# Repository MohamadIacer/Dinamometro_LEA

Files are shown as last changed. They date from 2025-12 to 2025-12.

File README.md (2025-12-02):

# Dinamometro_LEA
Repositório de desenvolvimento do sistema de dinamometria para turbinas em escala, utilizado pelo Laboratório de Energia e Ambiente da Universidade de Brasília.

Link com arquivos SolidWorks da montagem mecânica e peças individuais: https://1drv.ms/u/c/2880bb215aad6797/IQDlmrM-lfSOQbhDQPYtA1VkAWzMAm86arUpSsEFtpBo3BE?e=ooj1fM

Link com PDF do relatório da última iteração de desenvolvimento: https://1drv.ms/b/c/2880bb215aad6797/IQATOKx8Zu7TSKCGMIeG2nDvAc81WT-9CV8OO6a27Ivx5ow?e=Kimnmw

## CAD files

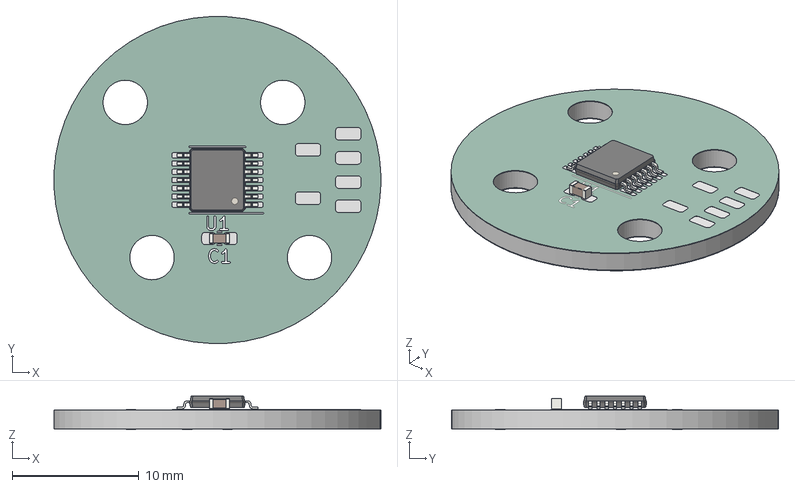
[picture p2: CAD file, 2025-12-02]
hardware/posicao/encoder_magnetico/encoder_magnetico.step
25.8 x 25.8 x 2.67 mm
TSSOP-14_4.4x5mm_P0.65mm
C_0603_1608Metric
encoder_magnetico_copper
encoder_magnetico_pad
encoder_magnetico_via
encoder_magnetico_silkscreen
encoder_magnetico_soldermask
encoder_magnetico_PCB

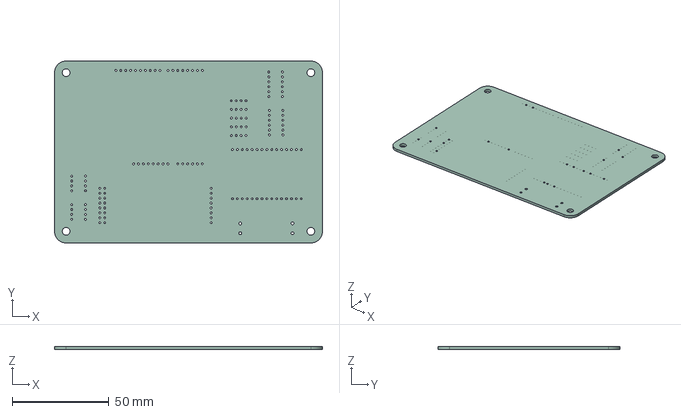
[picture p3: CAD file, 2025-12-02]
hardware/mb_geral/mb/mb1.step
138.5 x 94.0 x 1.51 mm

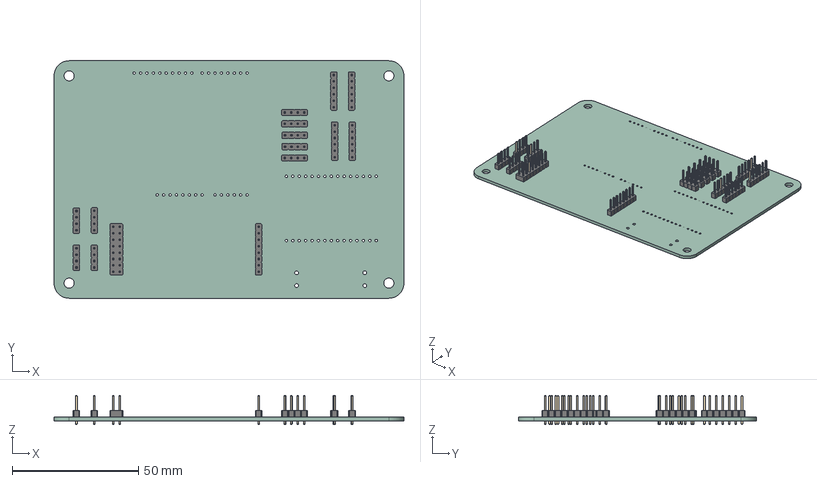
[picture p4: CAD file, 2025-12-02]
hardware/mb_geral/mb/mb.step
138.5 x 94.0 x 11.5 mm
PinHeader_1x04_P2.54mm_Vertical x 9
PinHeader_1x08_P2.54mm_Vertical
PinHeader_1x06_P2.54mm_Vertical x 4
PinHeader_2x08_P2.54mm_Vertical
mb_PCB

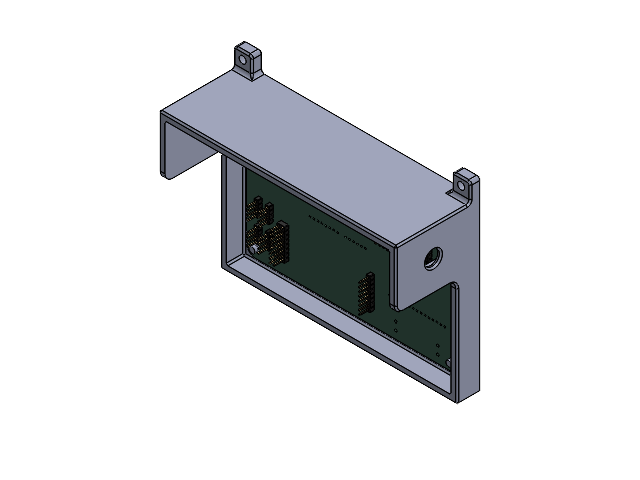
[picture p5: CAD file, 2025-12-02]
hardware/mb_geral/mb/Mont4.SLDASM
PinHeader_1x04_P2.54mm_Vertical.step x 9
PinHeader_1x08_P2.54mm_Vertical.step
PinHeader_1x06_P2.54mm_Vertical.step x 4
PinHeader_2x08_P2.54mm_Vertical.step
mb_PCB.step
case

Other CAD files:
hardware/mb_geral/mb/case.SLDPRT
hardware/mb_geral/mb/case.STL
hardware/mb_geral/mb/mb.SLDASM

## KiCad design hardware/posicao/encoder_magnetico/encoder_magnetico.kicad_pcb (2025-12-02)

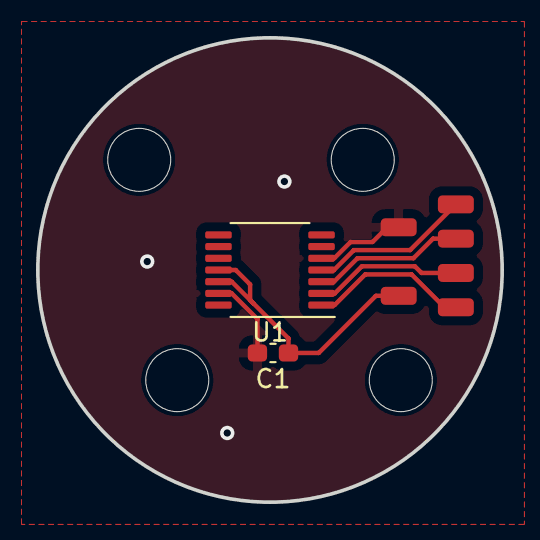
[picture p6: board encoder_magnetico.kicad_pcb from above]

Board: 2 copper layers, 25.8 x 25.8 mm, 12 parts (0 on the bottom side), 6 nets.

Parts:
3V3: Conn_01x01; SolderWirePad_1x01_SMD_1x2mm
C1: 100nF; C_0603_1608Metric_Pad1.08x0.95mm_HandSolder
CK: Conn_01x01; SolderWirePad_1x01_SMD_1x2mm
CS: Conn_01x01; SolderWirePad_1x01_SMD_1x2mm
GND: Conn_01x01; SolderWirePad_1x01_SMD_1x2mm
H1, H2, H3, H4: MountingHole; MountingHole_3.5mm
MI: Conn_01x01; SolderWirePad_1x01_SMD_1x2mm
MO: Conn_01x01; SolderWirePad_1x01_SMD_1x2mm
U1: AS5047D; TSSOP-14_4.4x5mm_P0.65mm

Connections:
3v3: 3V3.1, C1.1, U1.11 (VDD), U1.12 (VDD3V3)
CLK: CK.1, U1.2 (CLK)
CS: CS.1, U1.1 (~CS)
GND: C1.2, GND.1, U1.5 (TST), U1.13 (GND)
MISO: MI.1, U1.3 (MISO)
MOSI: MO.1, U1.4 (MOSI)

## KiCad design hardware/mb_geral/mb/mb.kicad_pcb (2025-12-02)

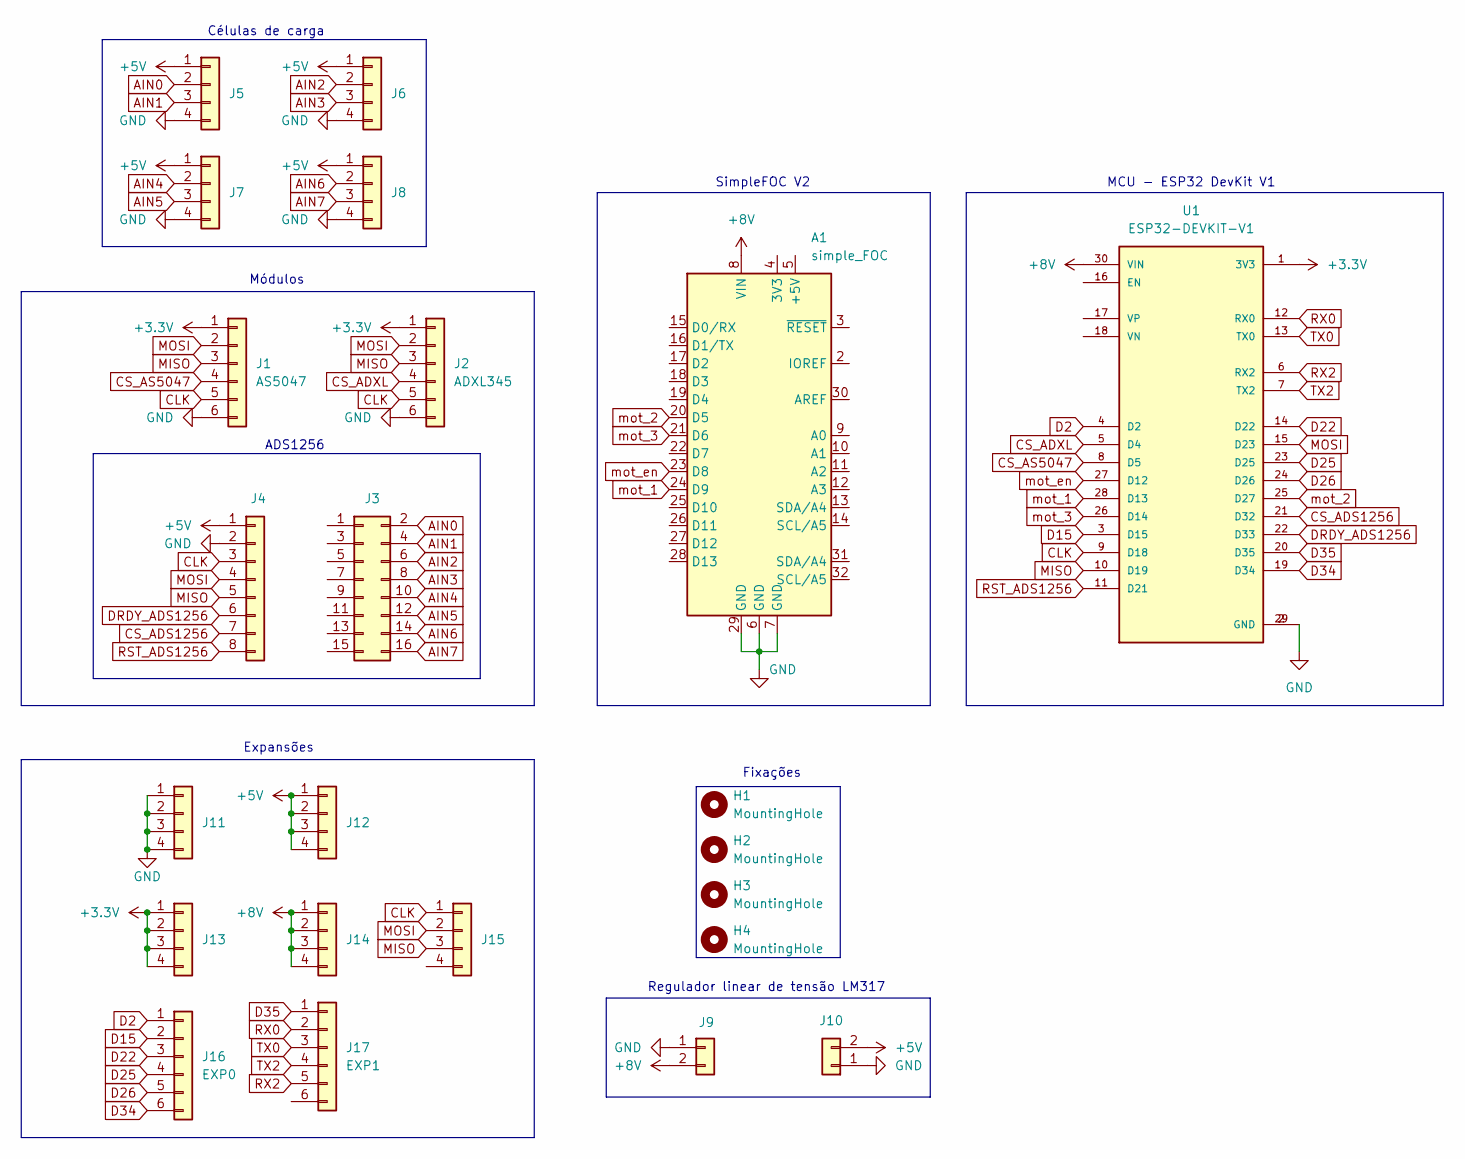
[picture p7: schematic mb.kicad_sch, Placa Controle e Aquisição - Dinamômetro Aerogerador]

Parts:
A1: simple_FOC; Arduino_UNO_R3
H1, H2, H3, H4: MountingHole; MountingHole_4mm
J1: AS5047; PinHeader_1x06_P2.54mm_Vertical
J2: ADXL345; PinHeader_1x06_P2.54mm_Vertical
J3: Conn_02x08_Top_Bottom; PinHeader_2x08_P2.54mm_Vertical
J4: Conn_01x08; PinHeader_1x08_P2.54mm_Vertical
J5, J6, J7, J8, J11, J12, J13, J14, J15: Conn_01x04; PinHeader_1x04_P2.54mm_Vertical
J9, J10: Conn_01x02; TerminalBlock_bornier-2_P5.08mm
J16: EXP0; PinHeader_1x06_P2.54mm_Vertical
J17: EXP1; PinHeader_1x06_P2.54mm_Vertical
U1: ESP32-DEVKIT-V1; MODULE_ESP32_DEVKIT_V1; PARTREV N/A

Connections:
+3.3V: J1.1, J2.1, J13.1, J13.2, J13.3, J13.4, U1.1 (3V3)
+5V: J4.1, J5.1, J6.1, J7.1, J8.1, J10.2, J12.1, J12.2, J12.3, J12.4
+8V: A1.8 (VIN), J9.2, J14.1, J14.2, J14.3, J14.4, U1.30 (VIN)
AIN0: J3.2, J5.2
AIN1: J3.4, J5.3
AIN2: J3.6, J6.2
AIN3: J3.8, J6.3
AIN4: J3.10, J7.2
AIN5: J3.12, J7.3
AIN6: J3.14, J8.2
AIN7: J3.16, J8.3
CLK: J1.5, J2.5, J4.3, J15.1, U1.9 (D18)
CS_ADS1256: J4.7, U1.21 (D32)
CS_ADXL: J2.4, U1.5 (D4)
CS_AS5047: J1.4, U1.8 (D5)
D2: J16.1, U1.4 (D2)
D15: J16.2, U1.3 (D15)
D22: J16.3, U1.14 (D22)
D25: J16.4, U1.23 (D25)
D26: J16.5, U1.24 (D26)
D34: J16.6, U1.19 (D34)
D35: J17.1, U1.20 (D35)
DRDY_ADS1256: J4.6, U1.22 (D33)
GND: A1.6 (GND), A1.7 (GND), A1.29 (GND), J1.6, J2.6, J4.2, J5.4, J6.4, J7.4, J8.4, J9.1, J10.1, J11.1, J11.2, J11.3, J11.4, U1.2 (GND), U1.29 (GND)
MISO: J1.3, J2.3, J4.5, J15.3, U1.10 (D19)
MOSI: J1.2, J2.2, J4.4, J15.2, U1.15 (D23)
RST_ADS1256: J4.8, U1.11 (D21)
RX0: J17.2, U1.12 (RX0)
RX2: J17.5, U1.6 (RX2)
TX0: J17.3, U1.13 (TX0)
TX2: J17.4, U1.7 (TX2)
mot_1: A1.24 (D9), U1.28 (D13)
mot_2: A1.20 (D5), U1.25 (D27)
mot_3: A1.21 (D6), U1.26 (D14)
mot_en: A1.23 (D8), U1.27 (D12)

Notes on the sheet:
Células de carga
Expansões
SimpleFOC V2
Módulos
ADS1256
Fixações
MCU - ESP32 DevKit V1
Regulador linear de tensão LM317

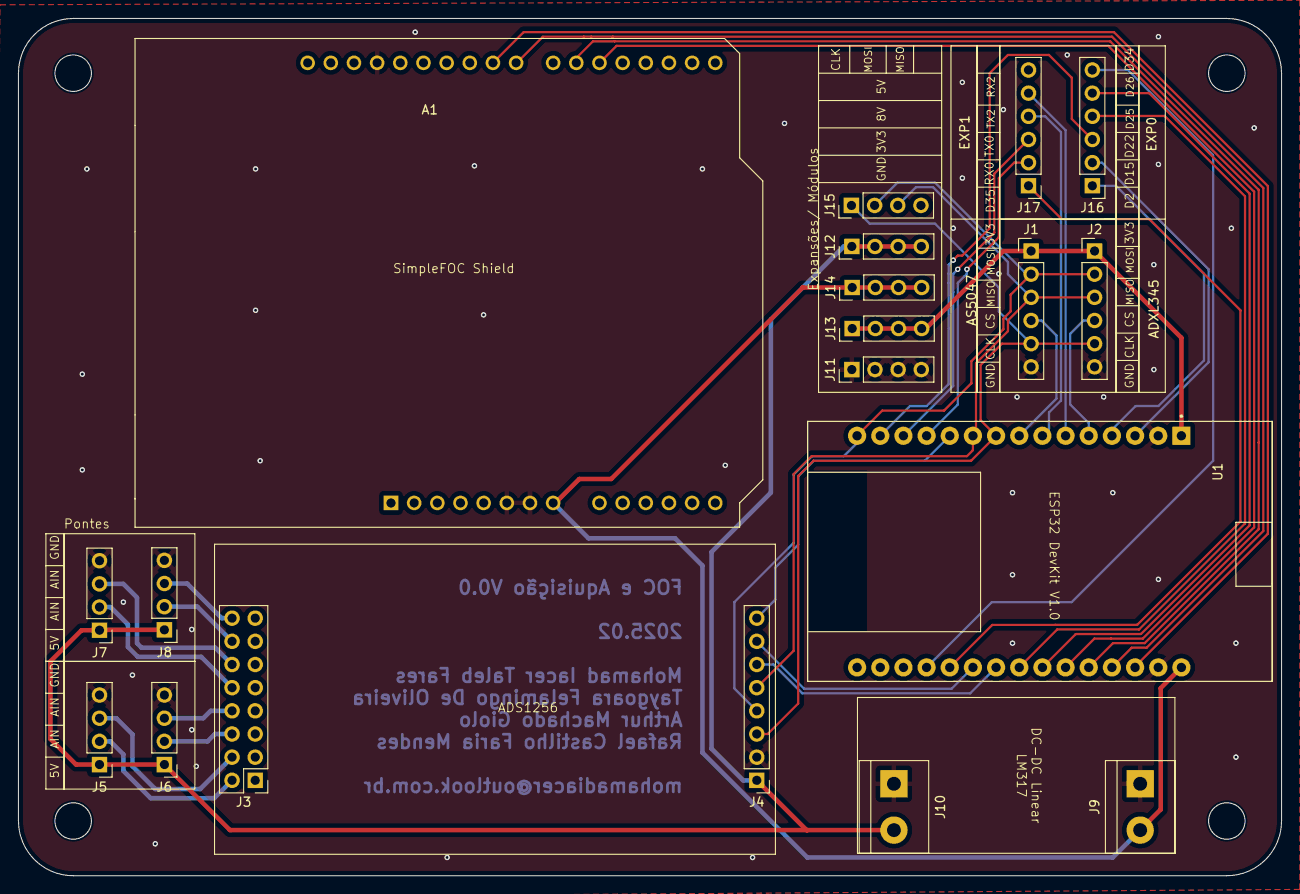
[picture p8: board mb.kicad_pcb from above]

Board: 2 copper layers, 138.5 x 94.0 mm, 23 parts (0 on the bottom side), 35 nets.

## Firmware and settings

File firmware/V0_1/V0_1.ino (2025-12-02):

/* ----------------------------------------------------------------------------
 *  Projeto:   Dinamômetro Aerogerador – Módulo de Controle e Aquisição
 *  Firmware:  Controle FOC + Aquisição ADS1256 + Encoder AS5047 + ADXL345
 *  Placa:     ESP32 DevKit V1 
 *  Versão:    v0.1
 *  Autor:     Mohamad Iacer Taleb Fares (LEA – UnB)
 *  Data:      2025.2
 *
 *  Descrição:
 *    Firmware responsável por:
 *      - Controle vetorial de campo (FOC) do atuador BLDC (SimpleFOC)
 *      - Leitura de posição via AS5047 (SPI)
 *      - Leitura dos extensômetros pelo ADS1256 (24 bits)
 *      - Leitura do acelerômetro ADXL345 (SPI)
 *      - Aquisição em múltiplos modos e envio de dados via serial
 *      - Execução distribuída em dois núcleos (Core 0 e Core 1)
 *
 *  Núcleos:
 *      Core 1 → Controle em tempo real (FOC)
 *      Core 0 → Aquisição, comunicação e processamento
 *
 *  Observações:
 *      - Todos os sensores operam no barramento VSPI.
 *      - Limite seguro de tensão do driver: 4.5 V.
 *      - Delays mínimos foram adicionados para evitar disputa no barramento SPI.
 *
 *  --------------------------------------------------------------------------- */


TaskHandle_t Task1;
#include <SimpleFOC.h>
#include <ADXL345_WE.h>
#include <ADS1256.h>
////////////////////////ADS1256

#define USE_SPI SPI


ADS1256 A(33, 0, 21, 32, 2.500, &USE_SPI);  //DRDY, RESET, SYNC(PDWN), CS, VREF(float), SPI bus.  //RP2040 Pico W - OK

long rawConversion = 0;  //24-bit raw value
float voltageValue = 0;  //human-readable floating point value

int pgaValues[7] = { PGA_1, PGA_2, PGA_4, PGA_8, PGA_16, PGA_32, PGA_64 };  //Array to store the PGA settings
float pgaSelection = 0;                                                     //Number used to pick the PGA value from the above array
float pgaSelection_old = 0;

String registers[11] = {
  "STATUS",
  "MUX",
  "ADCON",
  "DRATE",
  "IO",
  "OFC0",
  "OFC1",
  "OFC2",
  "FSC0",
  "FSC1",
  "FSC2"
};  //Array to store the registers

int registerToRead = 0;        //Register number to be read
int registerToWrite = 0;       //Register number to be written
int registerValueToWrite = 0;  //Value to be written in the selected register


////////////////////Acelerometro
bool spi = true;
ADXL345_WE myAcc = ADXL345_WE(4, spi);

//////////////////Simple FOC


// BLDC motor & driver instance
// BLDCMotor motor = BLDCMotor(pole pair number);
BLDCMotor motor = BLDCMotor(7);
// BLDCDriver3PWM driver = BLDCDriver3PWM(pwmA, pwmB, pwmC, Enable(optional));
BLDCDriver3PWM driver = BLDCDriver3PWM(13, 27, 14, 12);
MagneticSensorSPI sensor = MagneticSensorSPI(AS5047_SPI, 5);


//target variable
float target_velocity = 0;
float motorEnable = 0;
float velocidade_real = 0;
float posicao_eixo = 0;
float tempo_velocidade = 0;
float posicao_anterior = 0;
float tempo_velocidade_anterior = 0;
float mode = 0;
bool flag_case_1 = 0;
bool flag_case_2 = 0;
bool flag_case_3 = 0;
int teste = 0;

float channels[2];
xyzFloat raw, g;


// instantiate the commander
Commander command = Commander(Serial);
void doTarget(char* cmd) {
  command.scalar(&target_velocity, cmd);
}
void doFilter(char* cmd) {
  command.scalar(&motor.LPF_velocity.Tf, cmd);
}
void doControlP(char* cmd) {
  command.scalar(&motor.PID_velocity.P, cmd);
}
void doControlI(char* cmd) {
  command.scalar(&motor.PID_velocity.I, cmd);
}
void doControlD(char* cmd) {
  command.scalar(&motor.PID_velocity.D, cmd);
}
void doPGA(char* cmd) {
  command.scalar(&pgaSelection, cmd);
}
void doMode(char* cmd) {
  command.scalar(&mode, cmd);
}
void doVoltage(char* cmd) {
  command.scalar(&motor.voltage_limit, cmd);
}



void Task1code(void* parameter) {
  for (;;) {
    //Loop que roda no CORE0 da ESP32. Esse core é responsável por tarefas de comunicação, processamento e aquisição de dados.
    command.run();                      //Leitura e busca na serial por comandos
    posicao_eixo = motor.shaftAngle();  //A posição é calculada uma outra vez fora de loopFOC para maior precisão
    velocidade_real = motor.shaftVelocity();
    float torque_estimado = motor.voltage.q;


    //Testa se o PGA mudou para o set
    if (pgaSelection != pgaSelection_old) {
      A.setPGA(pgaValues[int(pgaSelection)]);
      pgaSelection_old = pgaSelection;
    }

    //switch case para configurar a aquisição de dados
    switch (int(mode)) {
      case 3:
        if (!flag_case_3) {
          A.sendDirectCommand(SELFCAL);
          flag_case_3 = 1;
        }
        break;
      case 2:
        myAcc.getGValues(&g);
        break;
      case 0:
        if (!flag_case_1) {
          A.setMUX(DIFF_0_1);
          flag_case_1 = 1;
          flag_case_2 = 0;
          flag_case_3 = 0;
        }
        teste = (A.readSingle());
        break;
      case 1:
        if (!flag_case_2) {
          A.setMUX(DIFF_2_3);
          flag_case_2 = 1;
          flag_case_1 = 0;
          flag_case_3 = 0;
        }
        teste = (A.readSingle());

        break;
    }
    //Print dos dados
    Serial.println(String(target_velocity) + "\t" + String(velocidade_real) + "\t" + String(posicao_eixo) + "\t" + String(g.x) + "\t" + String(g.y) + "\t" + String(g.z) + "\t" + String(teste) + "\t" + String(torque_estimado));

    vTaskDelay(1);  // solução prática para evitar que os núcleos da ESP32 façam competição por acessos a periféricos comuns (ex barramento SPI), dando tempo para o CORE1 acesse o que for necessário.
  }
}


void setup() {
  //Inciando comunicação serial com baud de 230400
  Serial.begin(115200);
  // enable more verbose output for debugging
  SimpleFOCDebug::enable(&Serial);

  // inicializa AS5047
  sensor.init();
  // link motor e sensor
  motor.linkSensor(&sensor);

  // Configuração do driver
  // Tensão de entrada da fonte no driver [V]
  driver.voltage_power_supply = 12;
  driver.init();
  // link do motor e driver
  motor.linkDriver(&driver);

  // set do tipo de controle do FOC
  motor.controller = MotionControlType::velocity;

  // Configurações e parâmetos do controlador
  motor.PID_velocity.P = 0.4f;
  motor.PID_velocity.I = 20;
  motor.PID_velocity.D = 0;
  // Tensão máxima entrege ao motor. Valores acima de 3 volts, com o motor utilizado pelo LEA, aquecem muito o driver
  motor.voltage_limit = 4.5;
  // jerk control com rampa de tensão
  motor.PID_velocity.output_ramp = 7000000;

  //Filtro passa baixa da leitura de velocidade. Ideal para o motor e sensor utilizados é 0.005f (empírico)
  motor.LPF_velocity.Tf = 0.005f;

  // inicializa o motor
  motor.init();
  // encontra zero do sensor e alinha o motor
  motor.initFOC();

  // possibilidades para o commander serial
  command.add('T', doTarget, "Setpoint velocidade");
  command.add('F', doFilter, "Filtro velocidade");
  command.add('P', doControlP, "Ganho proporcional");
  command.add('I', doControlI, "Ganho integrativo");
  command.add('D', doControlD, "Ganho derivativo");
  command.add('G', doPGA, "PGA ADC");
  command.add('M', doMode, "Modo de aquisição");
  command.add('C', doVoltage, "Tensão máxima");



  Serial.println(F("Freio iniciado"));
  _delay(1000);

  //Inicializa ADXL345
  if (!myAcc.init()) {
    Serial.println("ADXL345 não encontrado!");
  }
  myAcc.setDataRate(ADXL345_DATA_RATE_3200);
  delay(100);
  Serial.print("Data rate: ");
  Serial.print(myAcc.getDataRateAsString());
  myAcc.setRange(ADXL345_RANGE_2G);
  Serial.print("  /  g-Range: ");
  Serial.println(myAcc.getRangeAsString());
  Serial.println();

  //Inicializa ADS1256
  A.InitializeADC();

  //Set inicial do ADS1256, é ajustado posteriormente via Serial
  //PGA
  A.setPGA(PGA_64);  //0b00000000 - DEC: 0
  //--------------------------------------------

  //canal selecionado pelo multiplexador
  A.setMUX(DIFF_0_1);  //0b01100111 - DEC: 103
  //--------------------------------------------

  //Set DRATE (taxa de dados)
  A.setDRATE(DRATE_2000SPS);  //0b00010011 - DEC: 19
  //--------------------------------------------

  //Confirma os valores gravados nos registradores
  Serial.print("PGA: ");
  Serial.println(A.getPGA());
  delay(100);
  //--
  Serial.print("MUX: ");
  Serial.println(A.readRegister(MUX_REG));
  delay(100);
  //--
  Serial.print("DRATE: ");
  Serial.println(A.readRegister(DRATE_REG));
  delay(100);


  xTaskCreatePinnedToCore(
    //Atribui o task1 ao CORE0 da ESP32
    Task1code,
    "Task1",
    10000,
    NULL,
    0,
    &Task1,
    0);
  delay(1000);
}



void loop() {
  // loop que roda no CORE1 da ESP32. Esse core é responsável por todas as tarefas relacionadas ao controle do rotor e somente elas.

  motor.loopFOC();              //Abstração do controle
  motor.move(target_velocity);  //Setpoint da velocidade do eixo obtida pela serial
  vTaskDelay(0);
}

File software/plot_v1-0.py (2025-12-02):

import pandas as pd
import matplotlib.pyplot as plt
import numpy as np

# === CONFIGURAÇÕES CALIBRAÇÃO===
ARQUIVOS = [
    "calibracao_samples_20251129_190617.txt", #TXT para usar na calibração (quantos quiser)
    "calibracao_samples_20251129_233432.txt"
] 

COL_MASSA = "Massa[g]"
COL_LEITURA = "Leitura[int]"
BRAÇO_MM = 26 + 15       # mm → torque
# === CONFIGURAÇÕES ENSAIO===
D_rotor = 22e-2          # metros
V_vento = 7.0            # m/s
rho = 1.225              # kg/m³

coef_load = [0.004075/1000, 945.025/1000]
coef_freio = [11.394/1000, -1.577/1000]             #ignorar isso aqui

R_rotor = D_rotor/2

ARQUIVO = "aquisicao_20251119_173920.txt"            #TXT do ensaio

# ============================================================
# FUNÇÕES

def curva_de_calibracao(arquivos, col_massa, col_leitura, braco_mm):
    todos_dados = []
    todos_medios = []

    for arquivo in arquivos:

        # === LEITURA ===
        try:
            df = pd.read_csv(arquivo, sep="\t")
        except:
            df = pd.read_csv(arquivo, sep=",")

        # renomeia para garantir padronização
        df = df.rename(columns={
            df.columns[0]: col_massa,
            df.columns[1]: "Torque_original_ignore",
            df.columns[2]: col_leitura
        })

        df = df.dropna()

        # === CÁLCULO DO TORQUE USANDO A MASSA ===
        df["Torque[N.mm]"] = df[col_massa] / 1000 * 9.81 * braco_mm

        # === REMOVE OUTLIERS NA LEITURA ===
        Q1 = df[col_leitura].quantile(0.25)
        Q3 = df[col_leitura].quantile(0.75)
        IQR = Q3 - Q1
        df = df[(df[col_leitura] >= Q1 - 2*IQR) &
                (df[col_leitura] <= Q3 + 2*IQR)]

        # === AGRUPA POR MASSA ===
        agrupado = df.groupby(col_massa, as_index=False).agg({
            col_leitura: "mean",
            "Torque[N.mm]": "mean"
        })

        todos_dados.append(df[[col_leitura, "Torque[N.mm]"]])
        todos_medios.append(agrupado[[col_leitura, "Torque[N.mm]"]])

    # ================================================================
    # CURVA DE CALIBRAÇÃO FINAL
    # ================================================================
    dados = pd.concat(todos_dados, ignore_index=True)
    medios = pd.concat(todos_medios, ignore_index=True)

    x = medios[col_leitura].values
    y = medios["Torque[N.mm]"].values

    a, b = np.polyfit(x, y, 1)
    y_pred = a * x + b
    r2 = 1 - np.sum((y - y_pred)**2) / np.sum((y - y.mean())**2)

    # ================================================================
    # PLOT
    # ================================================================
    plt.figure(figsize=(8, 6))

    plt.scatter(dados[col_leitura], dados["Torque[N.mm]"],
                s=10, alpha=0.2, label="Dados brutos")

    plt.scatter(medios[col_leitura], medios["Torque[N.mm]"],
                s=50, edgecolor="k", label="Médias por massa")

    x_plot = np.linspace(min(x), max(x), 200)
    plt.plot(x_plot, a * x_plot + b, linewidth=3,
             label=f"T = {a:.6f}·ADC + {b:.6f}\nR²={r2:.5f}")

    plt.xlabel("Leitura ADC [inteiro]")
    plt.ylabel("Torque [N·mm]")
    plt.grid(True, linestyle="--", alpha=0.6)
    plt.legend()
    plt.tight_layout()
    plt.show()

    print(f"Curva final: T = {a:.6f}·ADC + {b:.6f}")
    print(f"R² = {r2:.5f}")

    # retorna se quiser usar depois
    return a, b, r2, dados, medios

# ============================================================
# MENU PRINCIPAL
# ============================================================
def moving_average(signal, window):
    pad = window // 2
    padded = np.pad(signal, pad, mode='reflect')
    kernel = np.ones(window)/window
    return np.convolve(padded, kernel, mode='valid')

def media_por_patamar(df, coluna_patamar, coluna_valor):
    """
    df: dataframe contendo os dados
    coluna_patamar: nome da coluna que indica o patamar (ex: 'omega_set')
    coluna_valor: coluna do sinal que você quer agrupar (ex: 'torque')
    """
    return df.groupby(coluna_patamar)[coluna_valor].mean()

def aplicar_calibracao(signal, coeficientes):
    """
    Aplica uma calibração polinomial aos dados.
    
    signal: array-like com os dados brutos (ex: tensões)
    coeficientes: lista com coeficientes do polinômio
                  no formato do numpy (do termo mais alto ao mais baixo)

    Ex: coeficientes = [a, b, c] → a*x^2 + b*x + c
    """
    # Cria o polinômio a partir dos coeficientes
    poly = np.poly1d(coeficientes)
    
    # Aplica o polinômio
    return poly(signal)

def calcular_cp(omega, torque, rho, V, diametro):
    """
    Calcula o coeficiente de potência (Cp) de um rotor.

    omega: velocidade angular (rad/s)
    torque: torque (N·m)
    rho: densidade do ar (kg/m³)
    V: velocidade do escoamento (m/s)
    diametro: diâmetro do rotor (m)
    """
    
    # potência mecânica
    P = torque * omega  # W
    
    # área varrida
    A = np.pi * (diametro/2)**2
    
    # potência disponível no vento (Betz denominator)
    P_disp = 0.5 * rho * A * V**3
    
    # Cp
    Cp = P / P_disp
    
    return Cp


def calcular_tsr(omega, V, diametro, eps=1e-12):
    """
    Calcula o TSR (tip-speed ratio).

    Parameters
    ----------
    omega : array-like or scalar
        Velocidade angular em rad/s.
    V : array-like or scalar
        Velocidade do escoamento em m/s.
    diametro : float
        Diâmetro do rotor em metros.
    eps : float, optional
        Valor mínimo para V para evitar divisão por zero (default 1e-12).

    Returns
    -------
    tsr : numpy.ndarray or float
        TSR correspondente (mesma forma de omega/V).
    """
    omega = np.asarray(omega)
    V = np.asarray(V)
    R = diametro / 2.0

    # evita divisão por zero: substitui V muito pequenos por eps
    V_safe = np.where(np.abs(V) < eps, eps, V)

    tsr = (omega * R) / V_safe

    # opcional: se V for ~0, podemos querer marcar com nan ao invés de valor grande
    tsr = np.where(np.abs(V) < eps, np.nan, tsr)

    return tsr
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
